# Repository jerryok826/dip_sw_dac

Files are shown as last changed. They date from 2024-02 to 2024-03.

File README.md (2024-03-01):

# dip_sw_dac

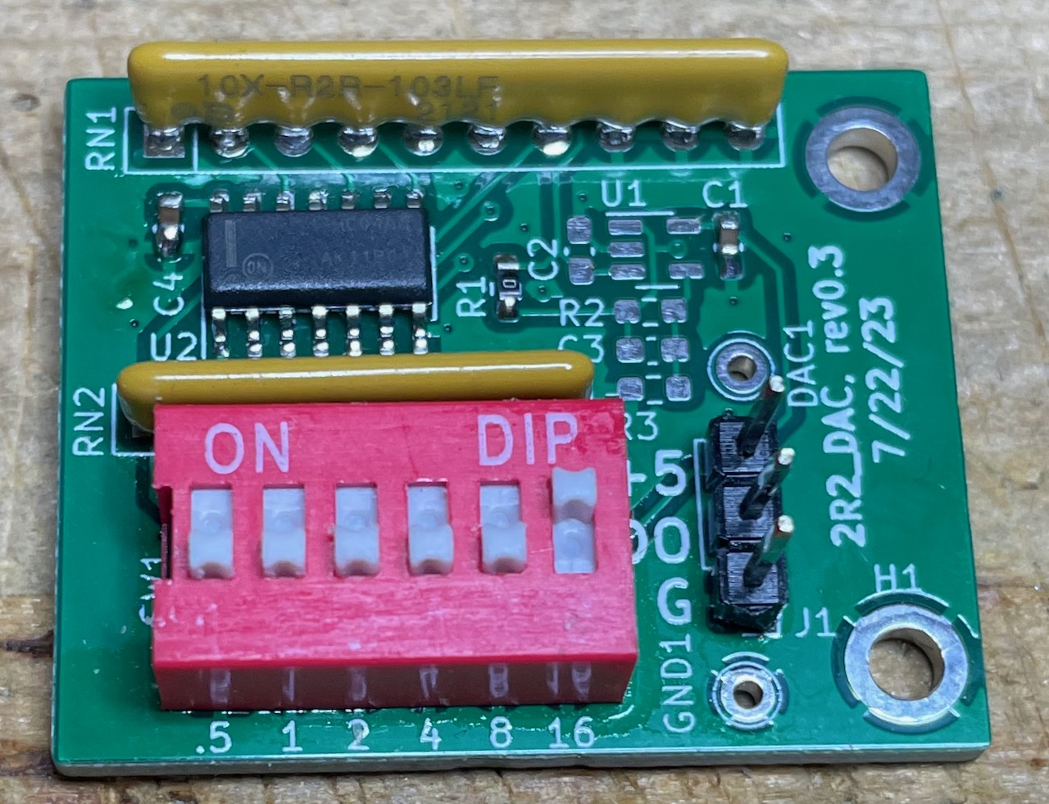
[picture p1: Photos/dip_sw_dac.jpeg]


## Project Description
Dip_sw_dac is an attempt to build a simple but precise digital potentiometer. It takes the VCC input of 5v or 3.3v and produces a selectable output in 64 steps. It can replace a three turn potentiometer in some adjustment use cases. The right most switch selects vcc/2. The left most switch is vcc/64. So for example if the two rightmost switches are on the board will output 3.75 Volts with a 5V VCC. Enabling the leftmost switch will increase the output by 0.078 volts or 1/64 of 5V.

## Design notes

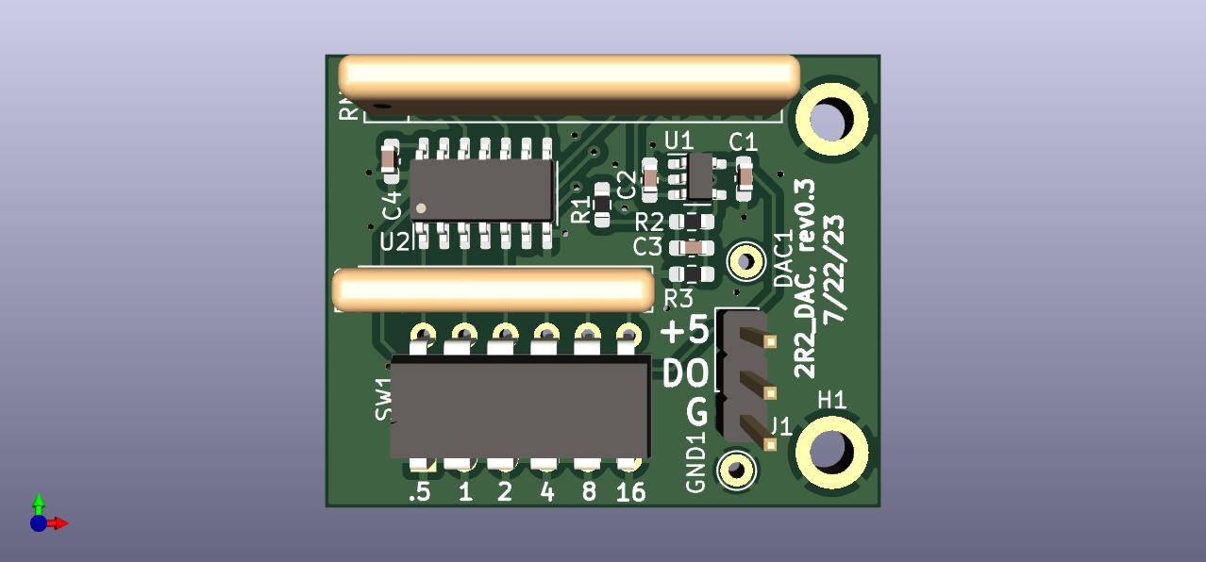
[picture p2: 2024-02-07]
Hardware/2r2_dac_r3.jpg

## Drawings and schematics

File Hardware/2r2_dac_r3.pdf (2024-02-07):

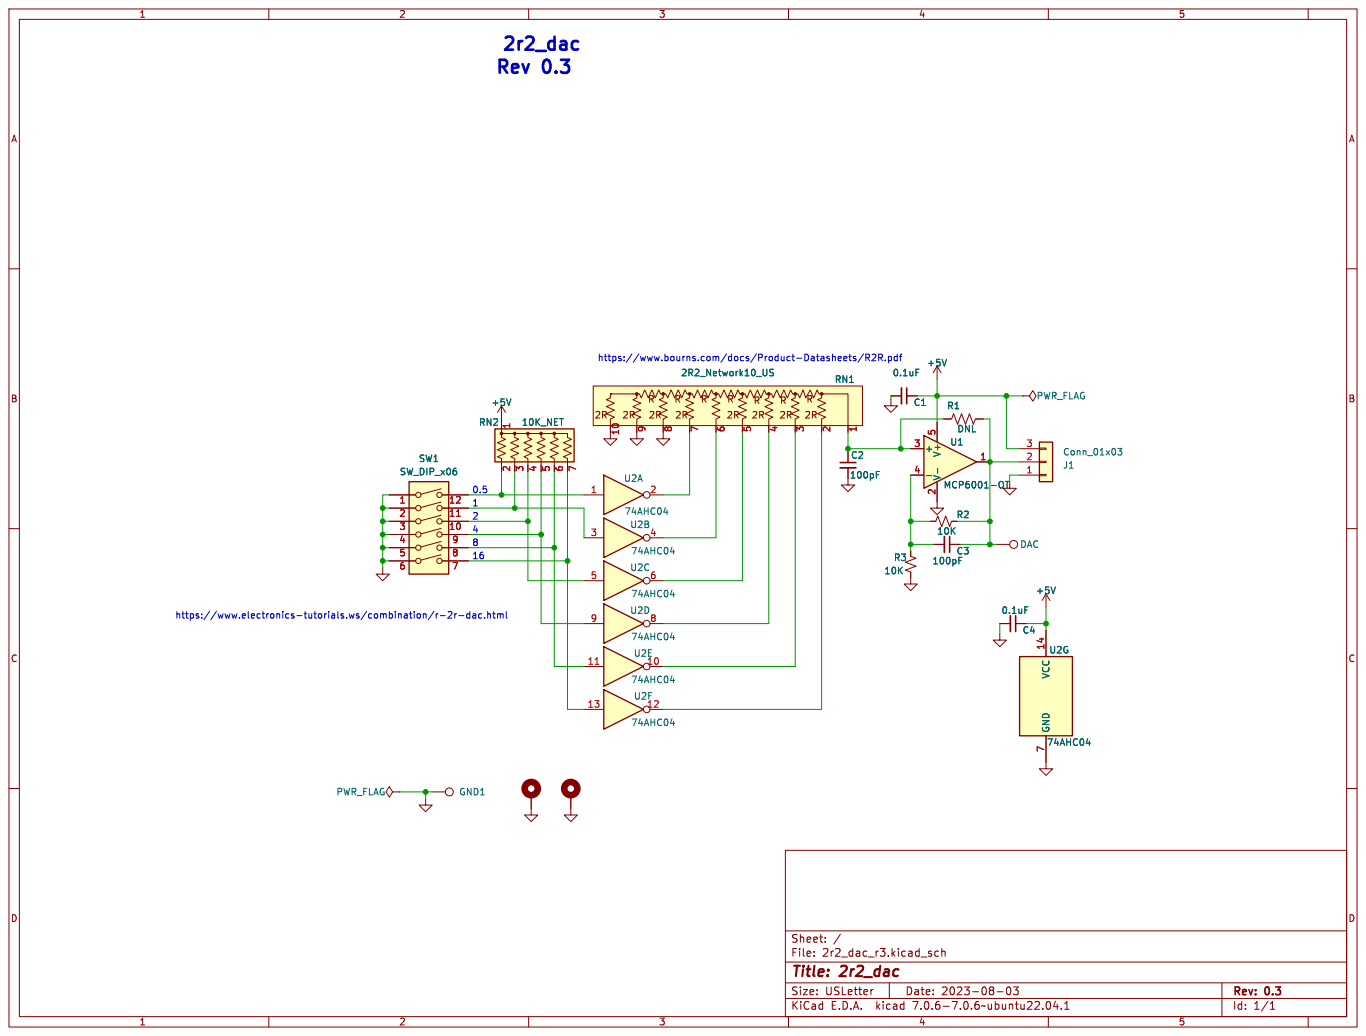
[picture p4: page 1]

https://www.bourns.com/docs/Product-Datasheets/R2R.pdf

https://www.electronics-tutorials.ws/combination/r-2r-dac.html

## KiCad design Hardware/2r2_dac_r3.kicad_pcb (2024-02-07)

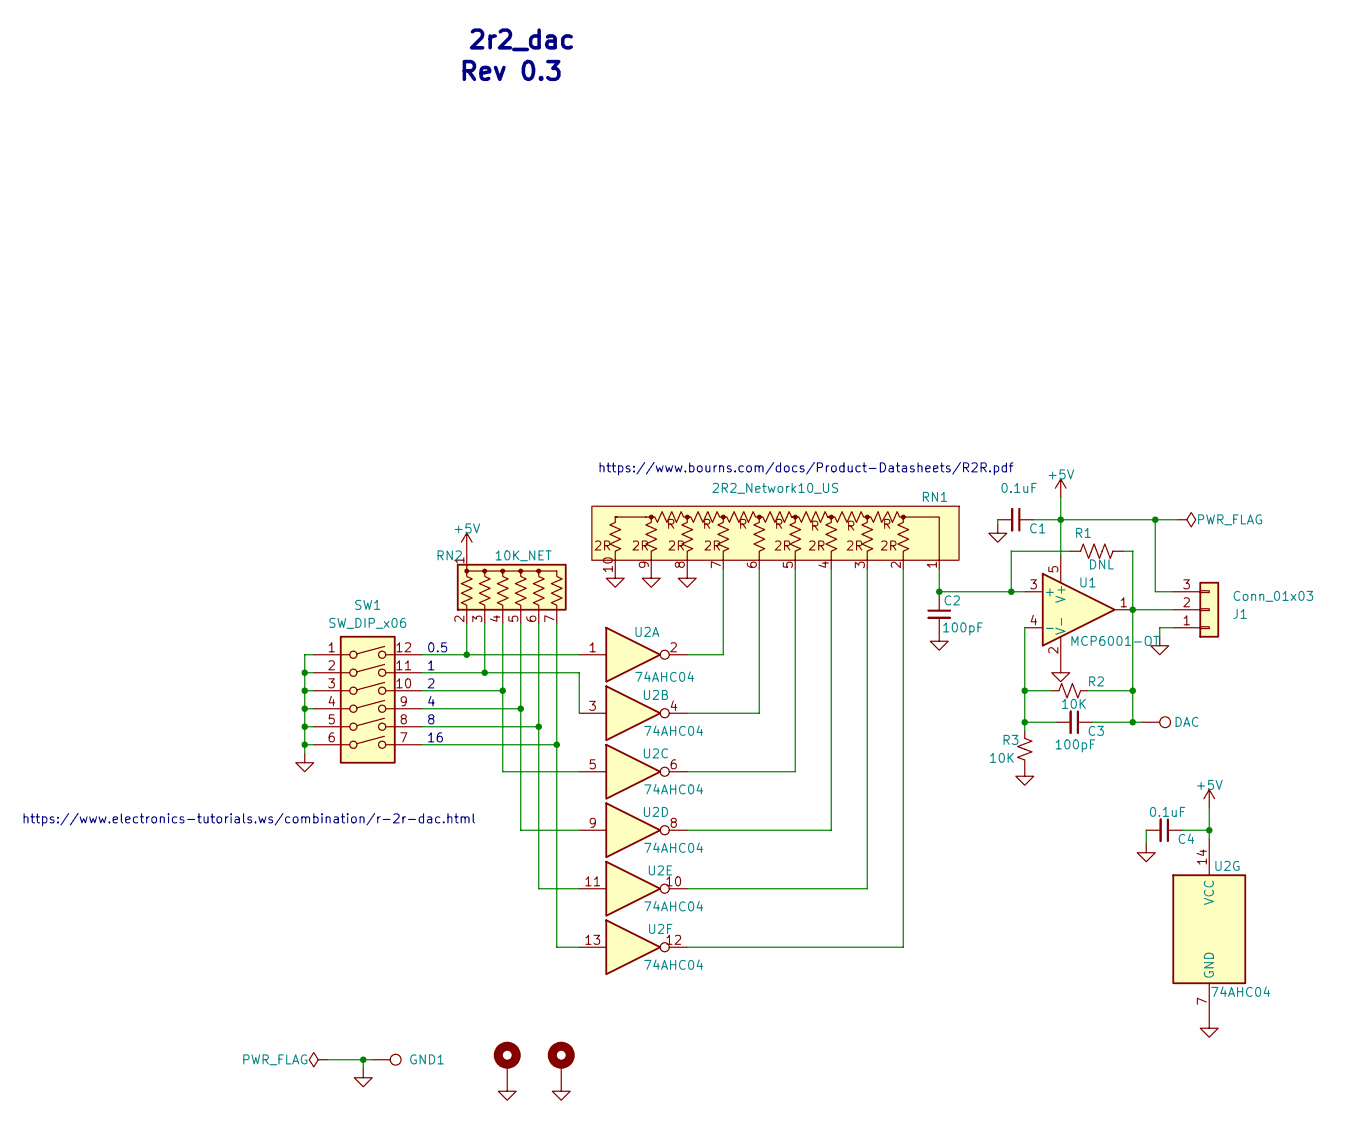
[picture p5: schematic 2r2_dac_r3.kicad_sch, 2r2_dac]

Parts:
C1, C4: 0.1uF; C_0603_1608Metric_Pad1.08x0.95mm_HandSolder
C2, C3: 100pF; C_0603_1608Metric_Pad1.08x0.95mm_HandSolder
DAC1: DAC; TestPoint_THTPad_D2.0mm_Drill1.0mm
GND1: GND1; TestPoint_THTPad_D2.0mm_Drill1.0mm
H1, H2: MountingHole_Pad; MountingHole_2.7mm_M2.5_ISO14580_Pad
J1: Conn_01x03; PinHeader_1x03_P2.54mm_Vertical
R1: DNL; R_0603_1608Metric_Pad0.98x0.95mm_HandSolder
R2, R3: 10K; R_0603_1608Metric_Pad0.98x0.95mm_HandSolder
RN1: 2R2_Network10_US; R_Array_SIP10
RN2: 10K_NET; R_Array_SIP7
SW1: SW_DIP_x06; DIP-12_W7.62mm
U1: MCP6001-OT; SOT-23-5
U2: 74AHC04; SOIC-14_3.9x8.7mm_P1.27mm

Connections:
+5V: C1.1, C4.1, J1.3, RN2.1 (common), U1.5 (V+), U2.14 (VCC)
GND: C1.2, C2.2, C4.2, GND1.1, H1.1, H2.1, J1.1, R3.1, RN1.8 (R7), RN1.9 (R8), RN1.10 (R10), SW1.1, SW1.2, SW1.3, SW1.4, SW1.5, SW1.6, U1.2 (V-), U2.7 (GND)
unnamed: C3.1, DAC1.1, J1.2, R1.2, R2.2, U1.1
unnamed: RN1.3 (2), U2.10
unnamed: C2.1, R1.1, RN1.1 (BIT_OUT), U1.3 (+)
unnamed: RN1.2 (MSB_1), U2.12
unnamed: RN1.4 (R3), U2.8
unnamed: RN1.5 (R4), U2.6
unnamed: RN1.6 (R5), U2.4
unnamed: RN1.7 (R6), U2.2
unnamed: RN2.2 (R1), SW1.12, U2.1
unnamed: RN2.3 (R2), SW1.11, U2.3
unnamed: RN2.4 (R3), SW1.10, U2.5
unnamed: RN2.5 (R4), SW1.9, U2.9
unnamed: RN2.6 (R5), SW1.8, U2.11
unnamed: RN2.7 (R6), SW1.7, U2.13
unnamed: C3.2, R2.1, R3.2, U1.4 (-)

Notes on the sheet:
0.5
https://www.bourns.com/docs/Product-Datasheets/R2R.pdf
2r2_dac
Rev 0.3
https://www.electronics-tutorials.ws/combination/r-2r-dac.html

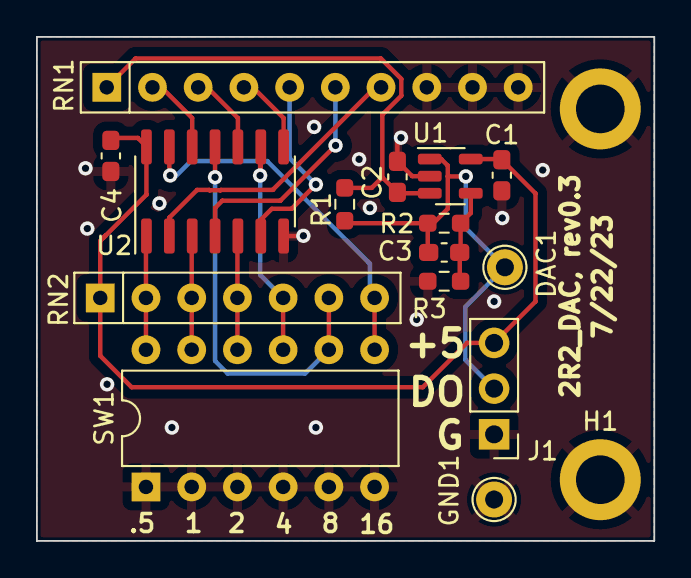
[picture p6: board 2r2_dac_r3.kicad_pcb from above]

Board: 2 copper layers, 34.3 x 28.0 mm, 17 parts (0 on the bottom side), 17 nets.
